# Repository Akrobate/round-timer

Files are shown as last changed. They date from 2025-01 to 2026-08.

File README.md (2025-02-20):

# Round Timer

## Api documentation

For detailed API documentation, please refer to the [API Documentation](./documentations/API%20Documentation.md).

## Webinterface

For detailed information about webinterface please refer to [Webinterface previews](./documentations/webinterface/webinterface.md).

## 3D Models previews

For detailed 3D Model documentation, please refer to the [3D Models Previews](./3D-model/README.md).

## 2D Models previews

For detailed 2D Model documentation, please refer to the [2D Models Previews](./2D-model/README.md).

## Web version of the functionnal round timer project

https://framagit.org/Akrobate/round-timer-js

### Web version preview

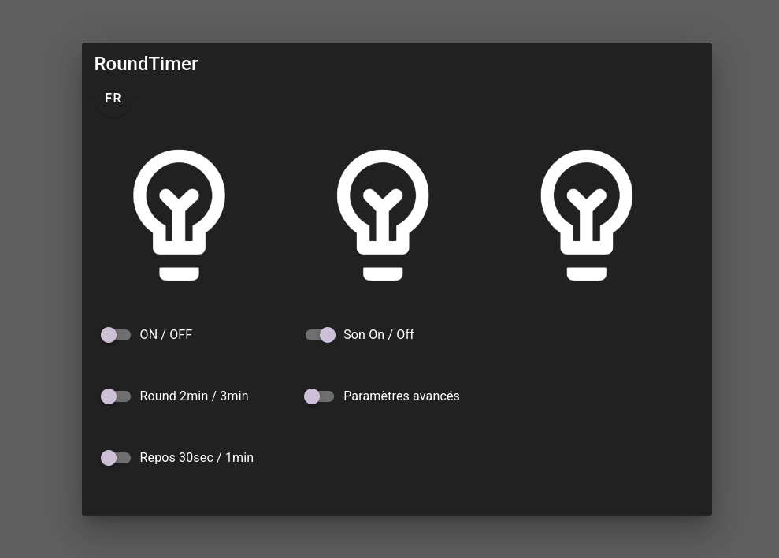
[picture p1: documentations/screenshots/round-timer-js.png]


## Configuration for hardwares

### Pinout esp8266
| Pin Name | Pin | Esp8266 names |Descirption |
|---|---|---|---|
| PIN_BUZZER | 14 | PIN_D5 | Buzzer signal |
| PIN_ON_OFF | 4 | PIN_D2 | Button on / off |
| PIN_ROUND_TIME | 5 | PIN_D1 | Button round time configuration  |
| PIN_REST_TIME | 13 | PIN_D7 | Button rest time configuration |
| PIN_NEOPIXEL_LED | 12 | PIN_D6 | Strip led pin |

### Led stripe type

Add or uncomment in lib/Lamps/Lamps.h

```cpp
#define SMALL_LED_STRIP
```

When `SMALL_LED_STRIP` is defined the strip of 3 leds is managed. Else a 12 leds strip is configured with 4 leds for each "lamp"

## Archived old project

`./code/archive/RoundTimerV1` Old version of the round timer. Without any web interface or configuration. Warning this version uses a deepsleep mode. Remains sleeping while on / off button is setted to off. To check the button status, it wakes up every 2 seconds for check of status. Starts if the state of button was passed to on. This configuration needs the RESET pin beeing connected to the wake up pin. It meens also that when it is connected the timer cannot be reprogrammed any more. So the best way for it is to put a removable strap.

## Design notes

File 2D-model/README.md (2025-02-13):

# 2D Models

## Laser engraving models

### Controls

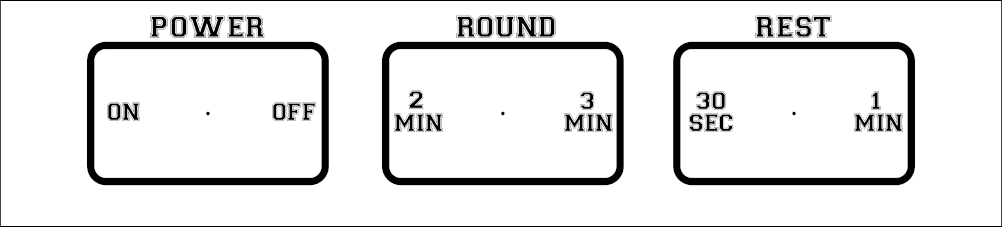
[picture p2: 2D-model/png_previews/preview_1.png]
Preview 1


### Logo

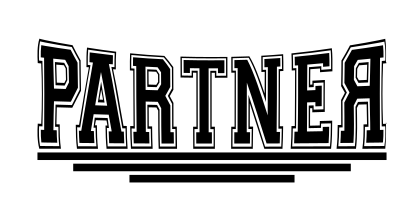
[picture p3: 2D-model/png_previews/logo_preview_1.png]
Logo Preview 1


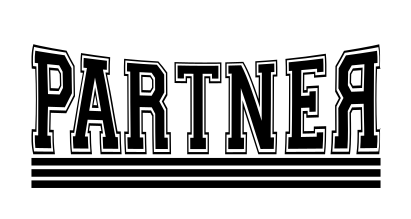
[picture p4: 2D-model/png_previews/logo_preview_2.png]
Logo Preview 2


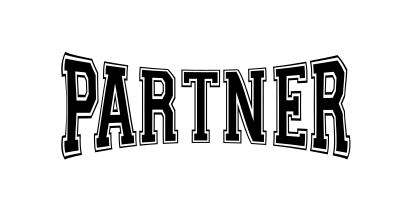
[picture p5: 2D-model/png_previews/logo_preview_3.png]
Logo Preview 3


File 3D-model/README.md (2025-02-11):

# 3D models preview

## Main part

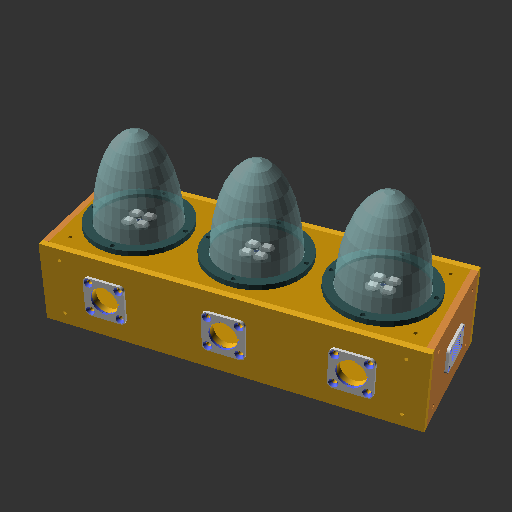
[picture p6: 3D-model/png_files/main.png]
Main component


## CNC Pieces

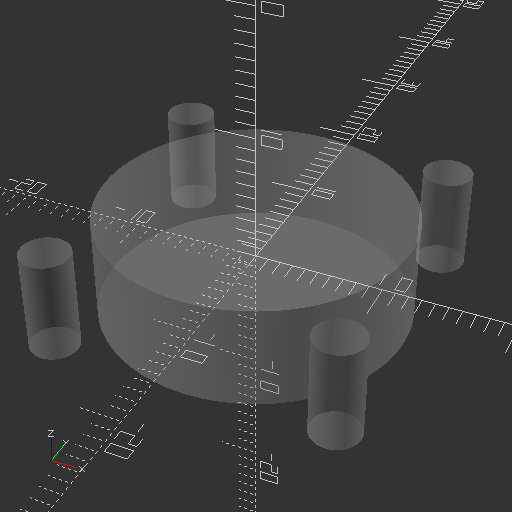
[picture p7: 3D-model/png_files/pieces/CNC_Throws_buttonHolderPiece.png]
CNC Throws buttonHolderPiece


## Pieces

### Angle Holder Piece

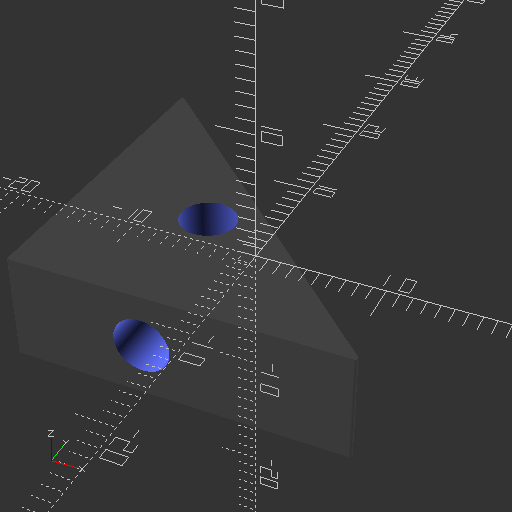
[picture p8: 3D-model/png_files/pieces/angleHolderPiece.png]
Angle Holder Piece


### Beeper Holder Piece

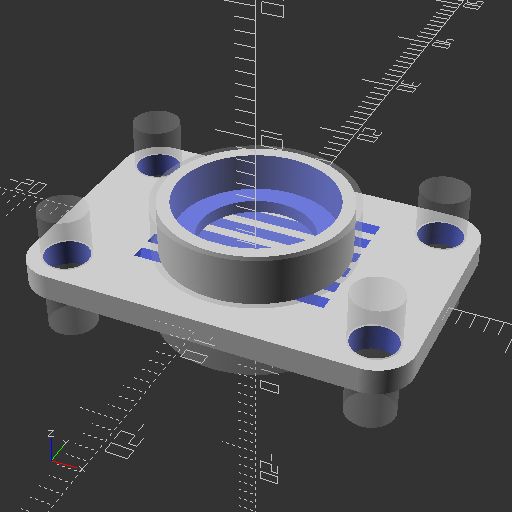
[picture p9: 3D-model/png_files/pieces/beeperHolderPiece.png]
Beeper Holder Piece


### Beeper Holder Back Piece

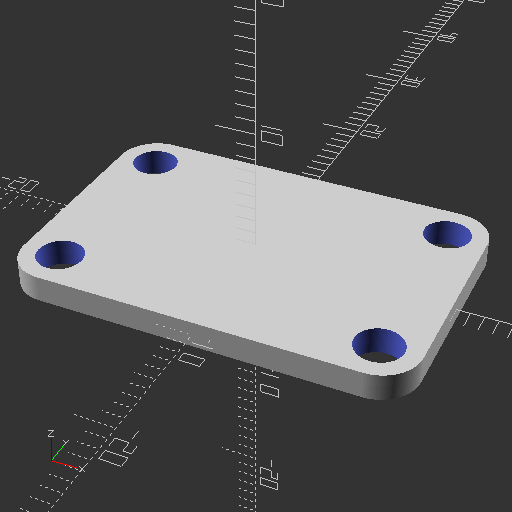
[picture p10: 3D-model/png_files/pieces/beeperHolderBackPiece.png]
Beeper Holder Back Piece


### Bolt Join Piece

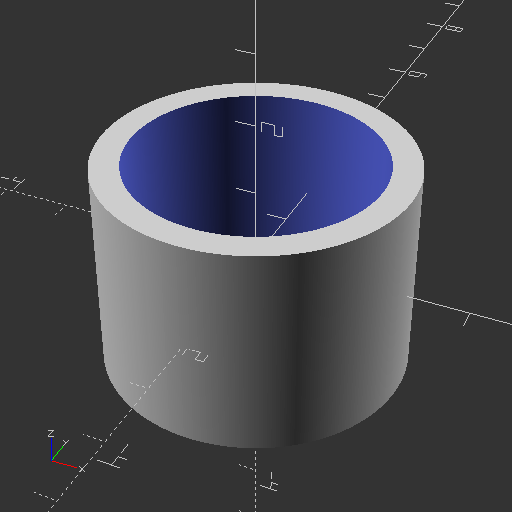
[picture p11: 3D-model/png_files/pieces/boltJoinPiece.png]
Bolt Join Piece


### Button Holder Piece

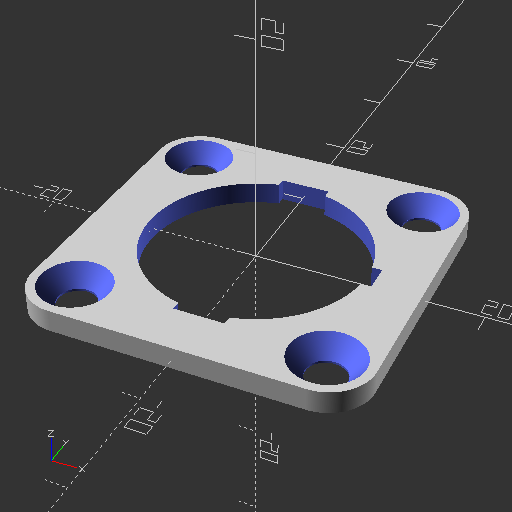
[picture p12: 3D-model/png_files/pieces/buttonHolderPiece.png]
Button Holder Piece


### Lampshade Holder Piece

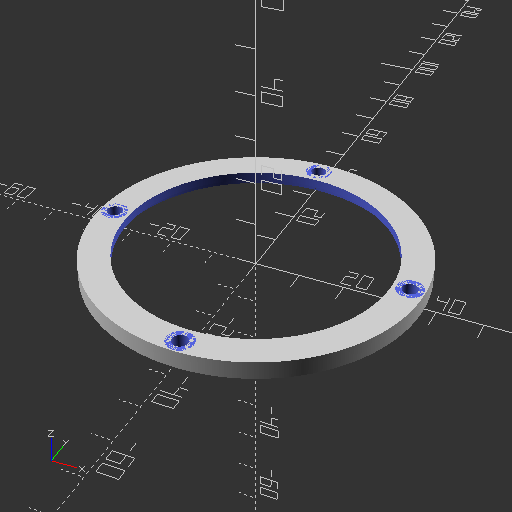
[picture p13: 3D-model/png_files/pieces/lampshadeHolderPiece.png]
Lampshade Holder Piece


### Lampshade Piece

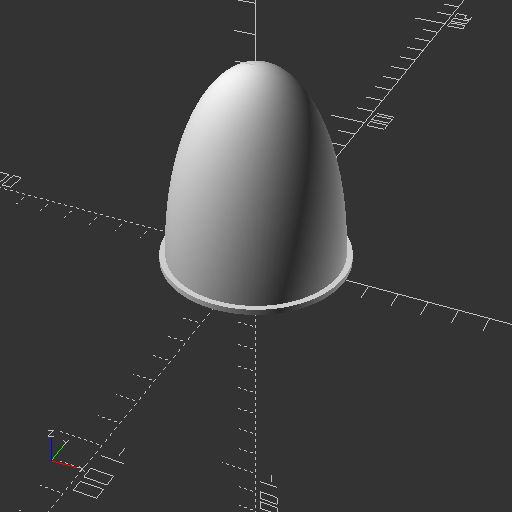
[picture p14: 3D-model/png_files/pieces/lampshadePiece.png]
Lampshade Piece


🏠 [Main](../README.md)

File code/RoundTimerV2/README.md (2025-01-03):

# Todo

- [ ] Upload firmware
- [ ] Round timer Configuration webinterface set to defaults
- [x] Save Wifi Configuration
- [x] Configuration save in file
- [x] Reset saved files (factory mode)
- [x] Presets Lamp
- [x] Webinterface Configuration Save loading button state
- [x] Disable beeper
- [x] sequence mode orienatation change
- [x] All lamps mode for round timer
- [x] Physical Buttons controller
- [x] prestart 5s timeout
- [x] Beeper mecanics

# Detected bugs

- [x] When preset is selected and round timer launched preset remains selected
- [x] Prestart time doesn't saves when restarts

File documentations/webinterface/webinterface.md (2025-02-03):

## WebInterface previews

### main page

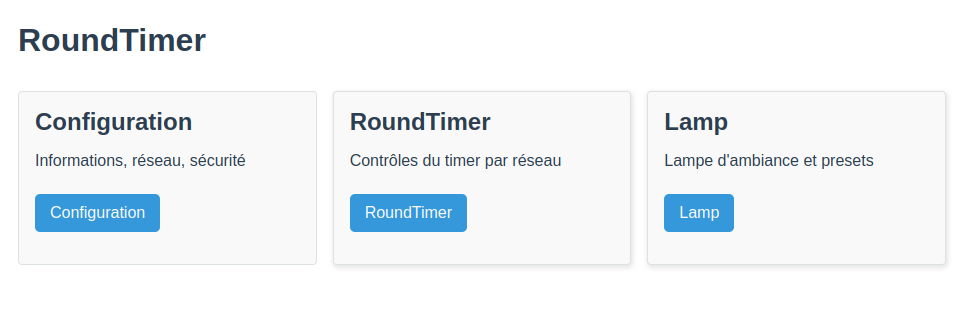
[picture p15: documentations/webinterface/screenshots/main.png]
main page


### Device configuration page

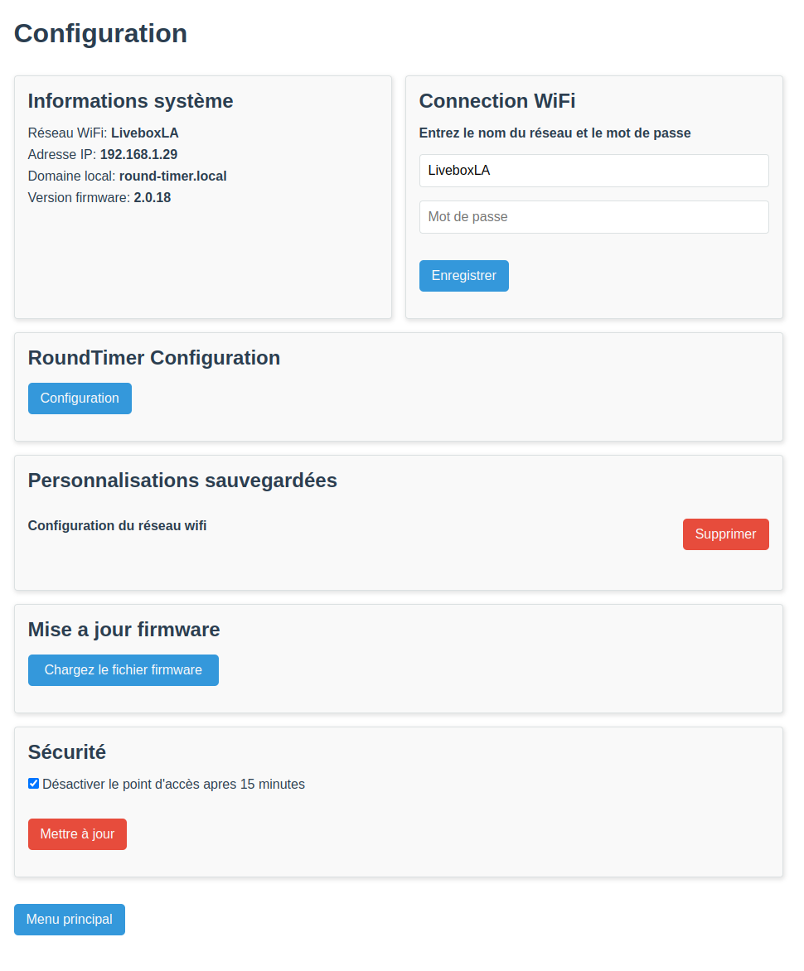
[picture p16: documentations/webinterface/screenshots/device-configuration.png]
Device configuration page


### Round Timer control

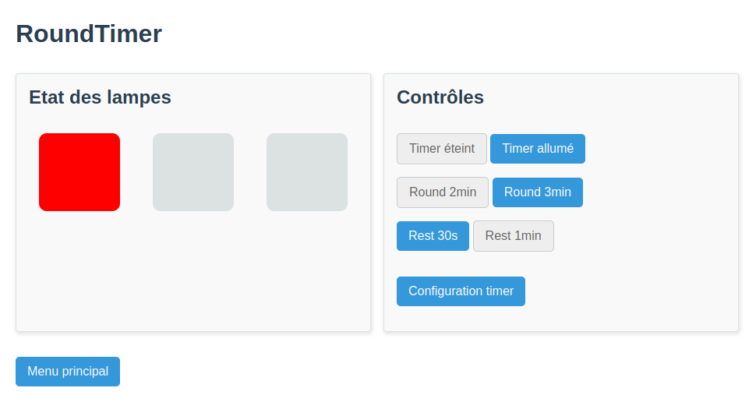
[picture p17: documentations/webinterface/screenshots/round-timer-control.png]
Round Timer control


### Round Timer configuration

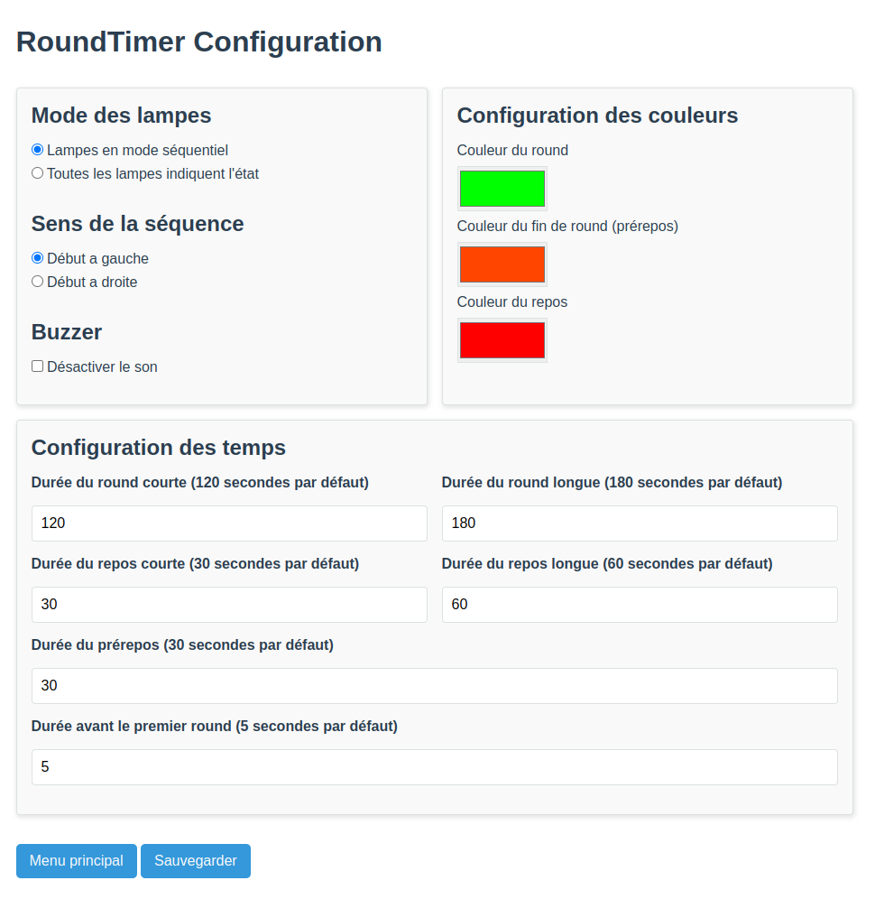
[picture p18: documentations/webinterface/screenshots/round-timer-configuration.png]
Round Timer configuration


### Round Timer Lamp

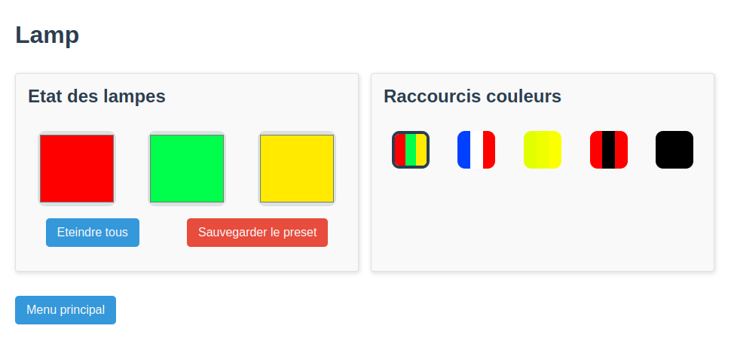
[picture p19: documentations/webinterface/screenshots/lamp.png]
Round Timer Lamp


🏠 [Main](../../README.md)

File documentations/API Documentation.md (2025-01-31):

# RoundTimerV2 API Documentation

## Lamp control

### Set lamps color

```sh
curl -X POST -d "lamp_0_color=#ff0000&lamp_1_color=#00ff00&lamp_2_color=#0000ff" http://192.168.1.29/api/lamps
```

### Put all lamps off

```sh
curl -X POST http://192.168.1.29/api/lamps-off
```

### Preset save

```sh
curl -X POST -d "index=0&lamp_0_color=#ff0000&lamp_1_color=#00ff00&lamp_2_color=#0000ff" http://192.168.1.29/api/lamps-presets
```

## Round timer controller

### Start round timer

```sh
curl -X POST -d "round_timer_state_is_running=true" http://192.168.1.29/api/controls
```

### Stop round timer

```sh
curl -X POST -d "round_timer_state_is_running=false" http://192.168.1.29/api/controls
```

### activate long round

```sh
curl -X POST -d "round_timer_state_is_round_long_duration=true" http://192.168.1.29/api/controls
```

### activate short round

```sh
curl -X POST -d "round_timer_state_is_round_long_duration=false" http://192.168.1.29/api/controls
```

### activate long rest

```sh
curl -X POST -d "round_timer_state_is_rest_long_duration=true" http://192.168.1.29/api/controls
```

### activate short rest

```sh
curl -X POST -d "round_timer_state_is_rest_long_duration=false" http://192.168.1.29/api/controls
```

## Round timer configuration

```sh
curl -X POST -d "round_timer_state_is_rest_long_duration=false" http://192.168.1.29/api/round-timer-configurations

```

### available params

- round_timer_mute : true / false
- round_timer_mode : integer
- round_timer_sequential_mode_order : integer
- round_timer_round_color : string
- round_timer_rest_color : string
- round_timer_prerest_color : string
- round_timer_round_long_duration : integer
- round_timer_round_short_duration : integer
- round_timer_rest_long_duration : integer
- round_timer_rest_short_duration : integer
- round_timer_prerest_duration : integer
- round_timer_prestart_duration : integer
- disconnect_access_point_delay : integer

## Round timer get business state

```sh
curl -X GET http://192.168.1.29/api/business-state
```

### Response should look like:

```json
{
    "device_mode": 1,
    "disconnect_access_point_delay": "string",
    "ap_ssid": "string",
    "sta_ssid": "string",
    "sta_password": "string",
    "sta_ip": "string",
    "sta_is_connected": "string",
    "sta_is_configured": "string",
    "mdns_host": "string",
    "mdns_is_configured": "string",
    "sta_credentials_file_exists": true,
    "configurations_file_exists": true,
    "lamps_presets_file_exists": true,
    "round_timer_mute": false,
    "round_timer_step": 1,
    "round_timer_mode": 1,
    "round_timer_sequential_mode_order": 1,
    "round_timer_round_color": "string",
    "round_timer_rest_color": "string",
    "round_timer_prerest_color": "string",

    "round_timer_round_long_duration": 1,
    "round_timer_round_short_duration": 1,
    "round_timer_rest_long_duration": 1,
    "round_timer_rest_short_duration": 1,
    "round_timer_prerest_duration": 1,
    "round_timer_prestart_duration": 1,

    "round_timer_state_is_running": true,
    "round_timer_state_is_round_long_duration": true,
    "round_timer_state_is_rest_long_duration": true,

    "lamp_0_color": "string",
    "lamp_1_color": "string",
    "lamp_2_color": "string",

    "firmware_version": "string",

    "lamp_preset_list": [
        ["#000000", "#000000", "#000000"],
        ["#000000", "#000000", "#000000"],
        ["#000000", "#000000", "#000000"],
        ["#000000", "#000000", "#000000"],
        ["#000000", "#000000", "#000000"]
    ]
}

```

## Credentials set

```sh
curl -X POST -d "sta_ssid=ssid_value&sta_password=password_value" http://192.168.1.29/api/sta-credentials
```

🏠 [Main](../README.md)

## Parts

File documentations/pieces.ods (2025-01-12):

 |  | Prix lot | Quantité lot | Prix unitaire |  | Nbr nécessaire | Cout
Controller | https://www.amazon.fr/AZDelivery-D1-Mini-d%C3%A9veloppement-compatible/dp/B0754W6Z2F | 19,99 | 5 | 3,998 |  | 1 | 3,998
Leds puissantes | https://www.amazon.fr/BTF-LIGHTING-adressables-individuels-dissipateur-thermique/dp/B088K6C7TJ | 19,99 | 100 | 0,1999 |  | 3 | 0,5997
Inters 2 positions | https://www.amazon.fr/Heschen-Interrupteur-bascule-bornes-250-VAC/dp/B076VRHF8H | 6,99 | 5 | 1,398 |  | 3 | 4,194
Buzzer | https://www.amazon.fr/AZDelivery-Capteur-dalarme-Arduino-compris/dp/B07ZYVH6XM | 6,49 | 5 | 1,298 |  | 1 | 1,298
Alim 220 / 5V | https://www.amazon.fr/AC-DC-700mA-Power-Supply-Module/dp/B08KH82YK1 | 16,36 | 5 | 3,272 |  | 1 | 3,272
Prise | https://www.amazon.fr/dp/B08TWM1LQ6 | 11,89 | 10 | 1,189 |  | 1 | 1,189
 | Proto total price | 81,71 |  |  | Total |  | 14,5507

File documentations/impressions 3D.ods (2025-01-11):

Nom du fichier | poids (g) | Filament | Prix (€) bobine 1kg | Layer (mm) | Prix (€) materiaux pièce | quantité | Prix (€)
buttonHolderPiece | 1,1 | PLA Black | 23,99 | 0,1 | 0,026389 | 3 | 0,079167
lampshadeHolderPiece | 5 | PLA Black | 23,99 | 0,1 | 0,11995 | 3 | 0,35985
facade-holder-8266-D1-piece | 4 | PLA Black | 23,99 | 0,1 | 0,09596 | 1 | 0,09596
beeperHolderPiece | 1 | PLA Black | 23,99 | 0,1 | 0,02399 | 1 | 0,02399
beeperHolderBackPiece | 1 | PLA Black | 23,99 | 0,1 | 0,02399 | 1 | 0,02399
angleHolderPiece | 2,2 | PLA Black | 23,99 | 0,1 | 0,052778 | 8 | 0,422224
lampshadeHolderPiece | 17 | PLA Transparent | 23,99 | 0,1 | 0,40783 | 3 | 1,22349
SmallboltJoinPiece | 0,1 | PLA Transparent | 23,99 | 0,1 | 0,002399 | 3 | 0,007197
boltJoinPiece | 0,1 | PLA Transparent | 23,99 | 0,1 | 0,002399 | 3 | 0,007197
 |  |  |  |  |  | Total | 2,243065

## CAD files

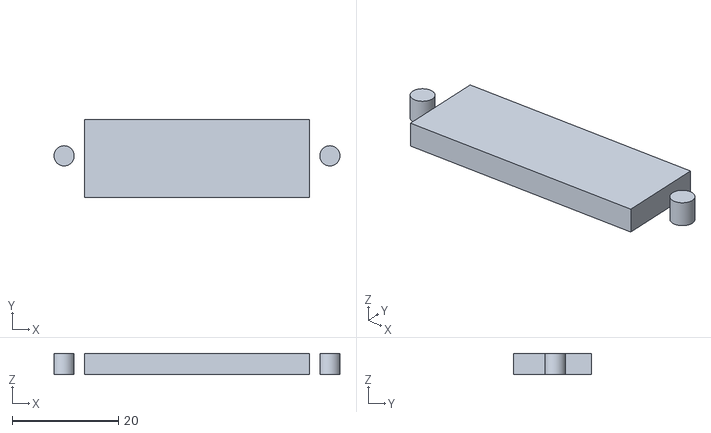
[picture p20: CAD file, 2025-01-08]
3D-model/stl_files/throws-holder-external-fix.stl
53.8 x 14.7 x 4.00

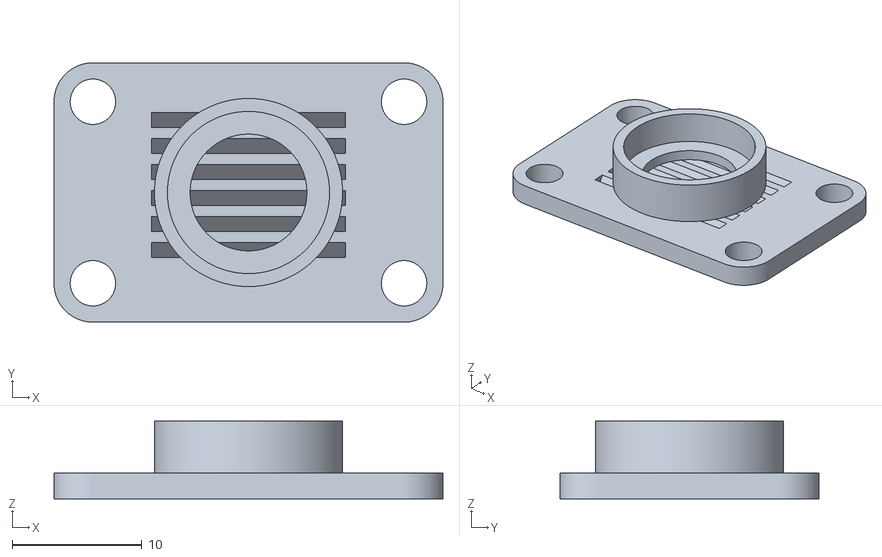
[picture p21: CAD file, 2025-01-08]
3D-model/stl_files/beeperHolderPiece.stl
30.0 x 20.0 x 6.00

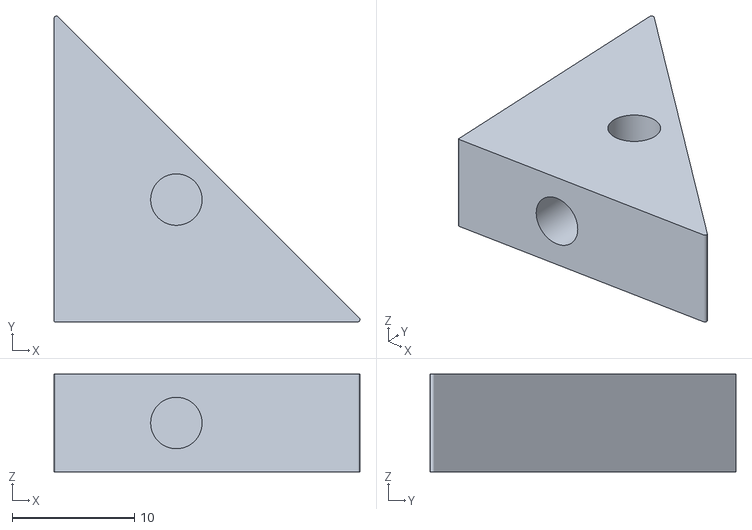
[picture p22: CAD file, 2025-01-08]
3D-model/stl_files/angleHolderPiece.stl
25.0 x 25.0 x 8.00

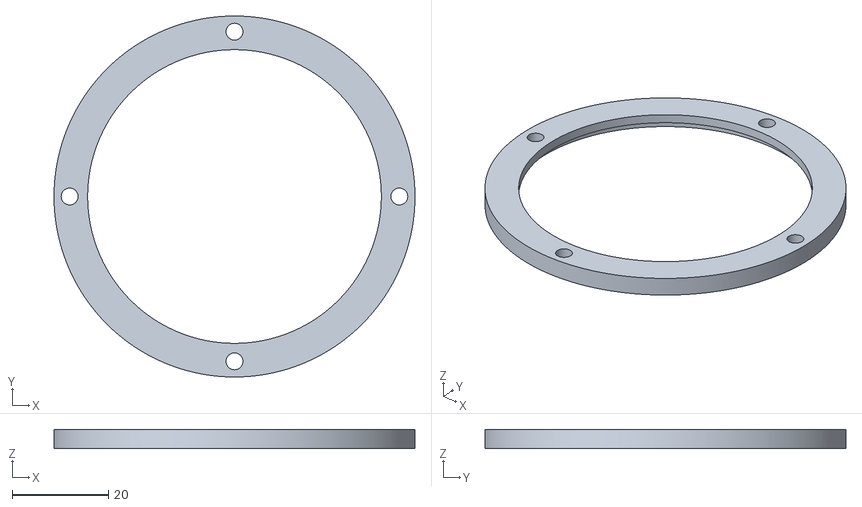
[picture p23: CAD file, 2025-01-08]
3D-model/stl_files/lampshadeHolderPiece.stl
75.0 x 75.0 x 4.00

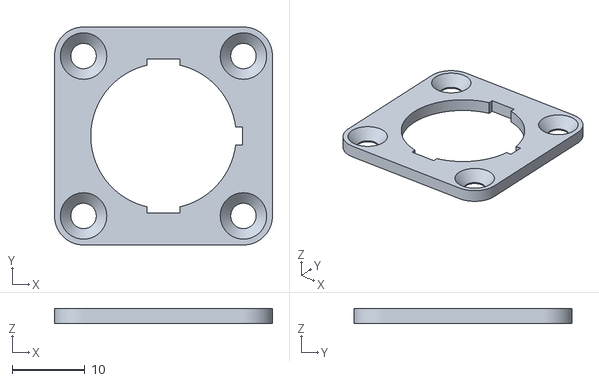
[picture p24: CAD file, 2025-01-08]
3D-model/stl_files/buttonHolderPiece.stl
30.0 x 30.0 x 2.00

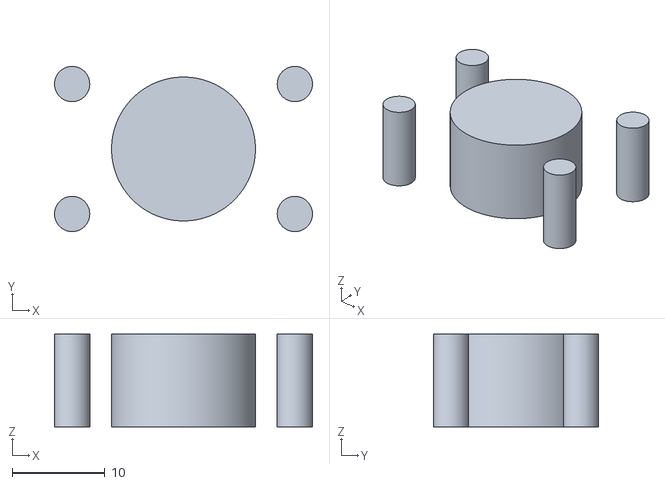
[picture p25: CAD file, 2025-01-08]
3D-model/stl_files/CNC_Throws_beeperHolderPiece.stl
27.8 x 17.8 x 10.0

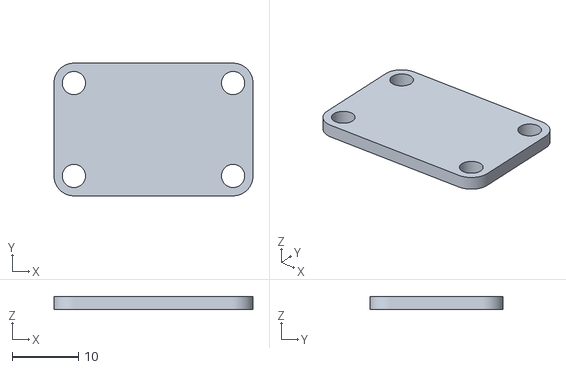
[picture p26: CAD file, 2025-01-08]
3D-model/stl_files/beeperHolderBackPiece.stl
30.0 x 20.0 x 2.00

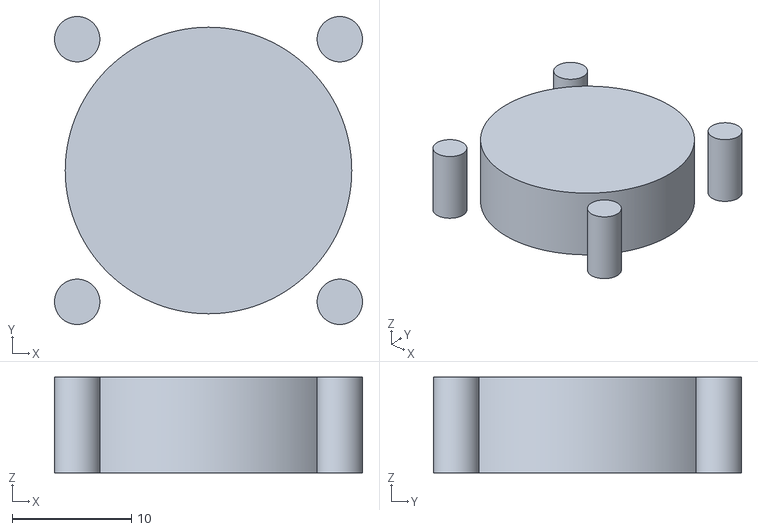
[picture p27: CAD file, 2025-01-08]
3D-model/stl_files/CNC_Throws_buttonHolderPiece.stl
25.8 x 25.8 x 8.00

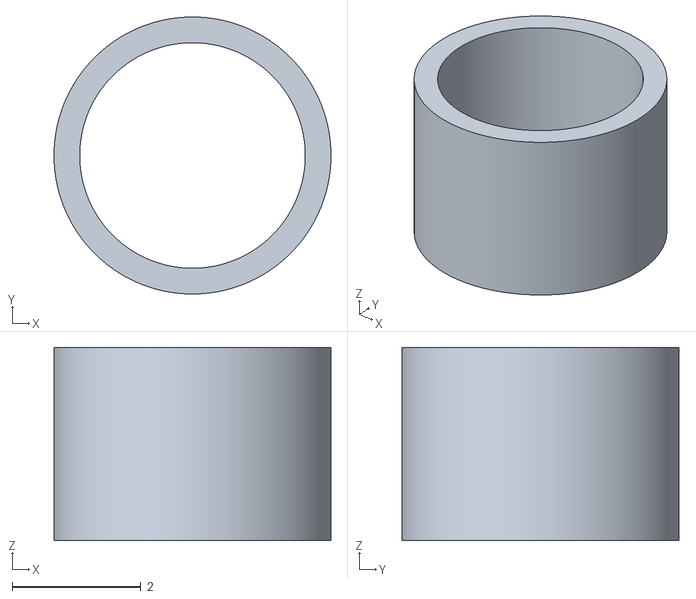
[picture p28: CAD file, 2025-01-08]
3D-model/stl_files/SmallboltJoinPiece.stl
4.30 x 4.30 x 3.00

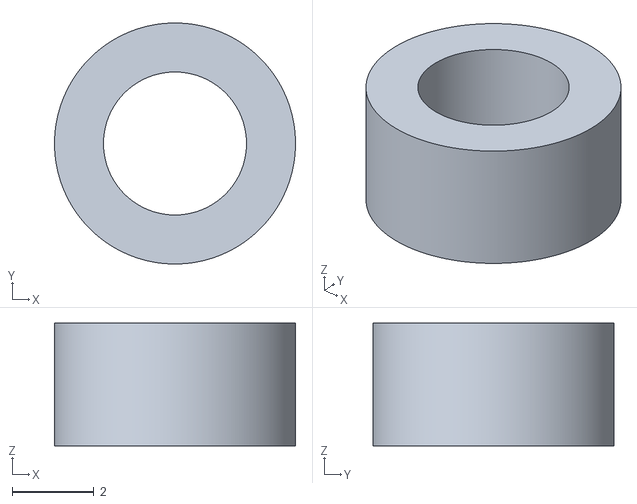
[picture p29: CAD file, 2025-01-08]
3D-model/stl_files/boltJoinPiece.stl
5.90 x 5.90 x 3.00

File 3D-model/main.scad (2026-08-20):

include <configurations/global.scad>


use <components/lampSetComponent.scad>
use <components/housingComponent.scad>
use <components/beeperComponent.scad>
use <components/holder8266D1Component.scad>
use <pieces/buttonHolderPiece.scad>

module main() {
    translate([0, 0, external_size.z])
        lampSetComponent();
    
    housingComponent();

    translate([beeperHolder_size.z + external_size.x,external_size.y / 2,external_size.z / 2])
        rotate([-90,0,90])
            beeperComponent();

    translate([external_size.x / 2, 0, external_size.z / 2])
        rotate([90,0,0])
            buttonHolderPiece();

    translate([external_size.x / 2 - space_between_lamps, 0, external_size.z / 2])
        rotate([90,0,0])
            buttonHolderPiece();


    translate([external_size.x / 2 + space_between_lamps, 0, external_size.z / 2])
        rotate([90,0,0])
            buttonHolderPiece();

    translate([0, external_size.y / 2, external_size.z / 2])
        rotate([0,0,-90])
            holder8266D1Component();
}


/**
 * @png
 * @colorscheme BeforeDawn
 */
main();

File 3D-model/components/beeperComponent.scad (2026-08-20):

include <../configurations/global.scad>

use <../pieces/beeperHolderPiece.scad>
use <../pieces/beeperHolderBackPiece.scad>


/**
 * beeperComponent
 * @name beeperComponent
 * @description beeperComponent
 * @type component
 */
module beeperComponent() {

    translate([0,0,beeperHolder_size.z / 2])
        beeperHolderPiece();

    translate([0,0,beeperHolder_size.z + beeperHolder_size.z / 2 + case_external_panes_thickness])
        beeperHolderBackPiece();
}


/**
 * @png
 * @colorscheme BeforeDawn
 */
beeperComponent();

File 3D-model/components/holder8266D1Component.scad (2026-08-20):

use <../pieces/espFacadeHolderPiece.scad>
use <../pieces/espFixationHolderPiece.scad>

/**
 * holder8266D1Component
 * @name holder8266D1Component
 * @description Full 8266 facade and holder
 * @type component
 */
 module holder8266D1Component(
   fixation_holder_position_y = 0.1,
   fixation_holder_position_z = 2,
   fixation_holder_position_x = 0
) {

   espFacadeHolderPiece();
   translate([
      fixation_holder_position_x,
      fixation_holder_position_y,
      fixation_holder_position_z
   ])
      espFixationHolderPiece();
}


/**
 * @png
 * @colorscheme BeforeDawn
 */
holder8266D1Component();

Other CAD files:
3D-model/components/housingComponent.scad
3D-model/components/lampComponent.scad
3D-model/components/lampSetComponent.scad
3D-model/configurations/global.scad
3D-model/enveloppes/CNC_Throws_buttonHolderPiece.scad
3D-model/enveloppes/beeperHolderThrowsEnveloppe.scad
3D-model/pieces/angleHolderPiece.scad
3D-model/pieces/backPanePiece.scad
3D-model/pieces/beeperHolderBackPiece.scad
3D-model/pieces/beeperHolderPiece.scad
3D-model/pieces/boltJoinPiece.scad
3D-model/pieces/bottomPanePiece.scad
3D-model/pieces/buttonHolderPiece.scad
3D-model/pieces/espFacadeHolderPiece.scad
3D-model/pieces/espFixationHolderPiece.scad
3D-model/pieces/frontPanePiece.scad
3D-model/pieces/lampshadeHolderPiece.scad
3D-model/pieces/lampshadePiece.scad
3D-model/pieces/leftPanePiece.scad
3D-model/pieces/rightPanePiece.scad
3D-model/pieces/subpieces/paneFixationThrows.scad
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

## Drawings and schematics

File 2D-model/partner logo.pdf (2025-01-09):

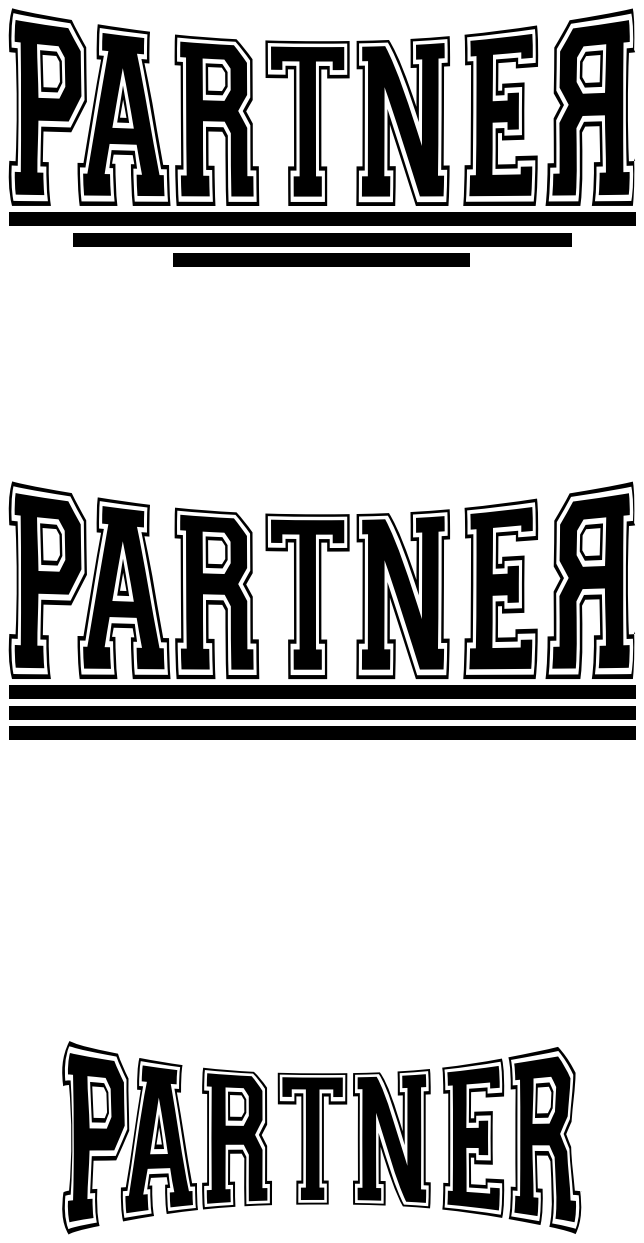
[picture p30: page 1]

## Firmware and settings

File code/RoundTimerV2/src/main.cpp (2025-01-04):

#include <Arduino.h>
#include <Lamps.h>
#include <TimerSequencer.h>
#include <RoundTimerServer.h>
#include <BusinessState.h>
#include <RoundTimer.h>
#include <Beeper.h>
#include <FacadeButtons.h>
#include <WifiService.h>

#define PIN_D1  5
#define PIN_D2  4
#define PIN_D4  2
#define PIN_D5  14
#define PIN_D6  12
#define PIN_D7  13
#define PIN_D8  15

#define SERVER_PORT           80

Lamps * lamps = new Lamps();
TimerSequencer * timer_sequencer = new TimerSequencer();
RoundTimerServer * server = new RoundTimerServer(SERVER_PORT);
BusinessState * business_state = new BusinessState();
RoundTimer * round_timer = new RoundTimer();
WifiService * wifi_service = new WifiService();
Beeper * beeper = new Beeper();
FacadeButtons * facade_buttons = new FacadeButtons();


void setup() {
    Serial.begin(74880); // 115200
    lamps->init();
    delay(1000);

    business_state->init();

    server->injectBusinessState(business_state);
    server->injectRoundTimer(round_timer);

    beeper->init();

    round_timer->injectBusinessState(business_state);
    round_timer->injectTimerSequencer(timer_sequencer);
    round_timer->injectLamps(lamps);
    round_timer->injectBeeper(beeper);
    round_timer->init();

    facade_buttons->injectBusinessState(business_state);
    facade_buttons->injectRoundTimer(round_timer);
    facade_buttons->init();

    wifi_service->injectBusinessState(business_state);
    wifi_service->init();

    server->init();
    server->begin();
}


void loop() {
    wifi_service->update();
    round_timer->update();
    facade_buttons->update();

    if (business_state->device_needs_restart) {
        delay(3000);
        ESP.restart();
    }
}

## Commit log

2024-12-24 Added round timer webinterface
2024-12-28 Cleaned code update fast led lib
2024-12-28 Working on round timer
2024-12-29 Added simple lamp inerface, round timer webinterface controlleer
2024-12-31 Rebuilt round timer webinterface
2025-01-08 Added 3D model
    [CNC_Throws_beeperHolderPiece.stl, CNC_Throws_buttonHolderPiece.scad, CNC_Throws_buttonHolderPiece.stl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]
2025-01-10 Added archive historic code round timer v1
2025-01-11 Added list of 3D printings
    [impressions 3D.ods]
2025-01-12 Added pieces file
    [pieces.ods]
2025-05-17 3D: Reorganizing 3D Files
    [angleHolderPiece.scad, lampshadePiece.scad, main.scad]
2025-08-23 Added new generate stl script
2026-05-19 Refactored components
    [lampComponent.scad, lampSetComponent.scad, main.scad]
2026-05-20 Normalizing code
    [lampComponent.scad, lampshadeHolderPiece.scad, lampshadePiece.scad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]
2026-05-21 3D cleaned angle holder
    [angleHolderPiece.scad]
2026-05-22 Documenting 3D code
    [angleHolderPiece.scad, lampshadePiece.scad]
2026-05-23 Moved dimentions to configuration file
    [global.scad, lampshadePiece.scad]
2026-05-24 Refactoring 3D model
    [global.scad, lampshadeHolderPiece.scad, lampshadePiece.scad]
2026-05-25 Preparing housing
    [bottomPanePiece.scad, global.scad, topPanePiece.scad]
2026-05-26 Workin gon housing
    [backPanePiece.scad, frontPanePiece.scad, housingComponent.scad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]
2026-05-27 HousingComponent work in progress
    [bottomPanePiece.scad, housingComponent.scad, leftPanePiece.scad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]
2026-05-28 Added front / back piece
    [backPanePiece.scad, frontPanePiece.scad, housingComponent.scad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]
2026-05-29 Removed debug block for housingComponent
    [global.scad, main.scad]
2026-05-30 positionning housing component
    [angleHolderPiece.scad, housingComponent.scad]
2026-05-31 Colorized housing
    [angleHolderPiece.scad, global.scad, housingComponent.scad]
2026-06-01 Throws positionned on panes
    [frontPanePiece.scad, global.scad]
2026-06-02 Added throws, fixed right offsets
    [angleHolderPiece.scad, backPanePiece.scad, frontPanePiece.scad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]
2026-06-03 Created subpiece to factorise squared throwed pane
    [leftPanePiece.scad, main.scad, paneFixationThrows.scad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]
2026-06-04 Positionning buttons
    [buttonHolderPiece.scad, main.scad]
2026-06-05 Positionning buttons throws
    [CNC_Throws_buttonHolderPiece.scad, buttonHolderPiece.scad, frontPanePiece.scad]
2026-06-06 Added 3 buttons throws
    [frontPanePiece.scad, global.scad, main.scad]
2026-06-07 Refactoring code, positionning throws
    [buttonHolderPiece.scad, frontPanePiece.scad, global.scad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]
2026-06-08 Refactored throws
    [CNC_Throws_buttonHolderPiece.scad, global.scad]
2026-06-09 Refactored paneFixationThrows
    [leftPanePiece.scad, paneFixationThrows.scad]
2026-06-10 Updated with throws
    [rightPanePiece.scad, squareThrowedPaneSubpiece.scad]
2026-06-11 Cleaning beeper holder pieces
    [CNC_Throws_buttonHolderPiece.scad, beeperHolderBackPiece.scad, beeperHolderPiece.scad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]
2026-06-12 Removed useless function params in components
    [beeperHolderThrowsEnveloppe.scad, lampSetComponent.scad, main.scad]
2026-06-13 Created and placed BeeperComponent
    [beeperComponent.scad, main.scad]
2026-06-14 Implemented thorows on right pane
    [housingComponent.scad, rightPanePiece.scad]
2026-06-14 esp holder placed
    [leftPanePiece.scad]
2026-06-15 Positionned microcontroller holder components
    [holder8266D1Component.scad, leftPanePiece.scad, main.scad]
2026-06-16 Added pieces wrappers for holder esp8266
    [espFacadeHolderPiece.scad, espFixationHolderPiece.scad, holder8266D1Component.scad]
2026-06-17 Anotating Pieces
    [angleHolderPiece.scad, backPanePiece.scad, beeperHolderBackPiece.scad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]
2026-06-18 Refacored boltJoin
    [boltJoinPiece.scad, global.scad]
2026-06-18 Added led module
    [main.scad]
2026-06-19 Positionned leds, and supports for LEDS
    [boltJoinPiece.scad, lampComponent.scad, lampSetComponent.scad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]
2026-06-20 Added top / bottom panes pieces throws
    [bottomPanePiece.scad, housingComponent.scad, topPanePiece.scad]
2026-06-21 Added cables and fixation throws
    [global.scad, topPanePiece.scad]
2026-06-25 Removing debug stuff, annotating components
    [beeperComponent.scad, holder8266D1Component.scad, housingComponent.scad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]
2026-08-20 Anotation components fixed, regenerated main.png
    [beeperComponent.scad, holder8266D1Component.scad, housingComponent.scad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]
